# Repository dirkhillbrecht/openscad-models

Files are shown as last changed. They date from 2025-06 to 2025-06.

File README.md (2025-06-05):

# openscad-models

This repository contains OpenSCAD models I created for various purposes and want to share with the public.
The models may be related or unrelated, they may have external dependencies (but I like to prevent that)
and they might be from totally different realms.
Please refer to the `README`s in the subdirectories for actual information on the respective models.

As of June 2025, I use the official OpenSCAD 2021.1 for design.
This is the baseline version for the models published here.

## Projects

* [Case for the Waveshare 7 inch IPS HDMI display with USB touch, audio and VGA connectors](waveshare-7-inch-display-case/README.md)

## License

The license for the models published here is usually [CC-BY-SA 4.0](https://creativecommons.org/licenses/by-sa/4.0/deed.en) unless specified differently for certain models.
Look for `LICENSE` files here or in the subdirectories.

## History

I started 3D printing and designing by the end of 2023.
I created a number of models over time which I partly published on platforms like Printables.
So far, I used my local version control for the files.

As time went by and the number of my models increased, I wanted to have a better way of publishing
the OpenSCAD source files and especially of their version control.
So I decided to create this repository on Github which contains all this stuff
and makes it available to the public.

Have fun!

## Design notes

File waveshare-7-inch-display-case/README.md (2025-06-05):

# Case for the Waveshare 7 inch IPS HDMI display with USB touch, audio and VGA connectors

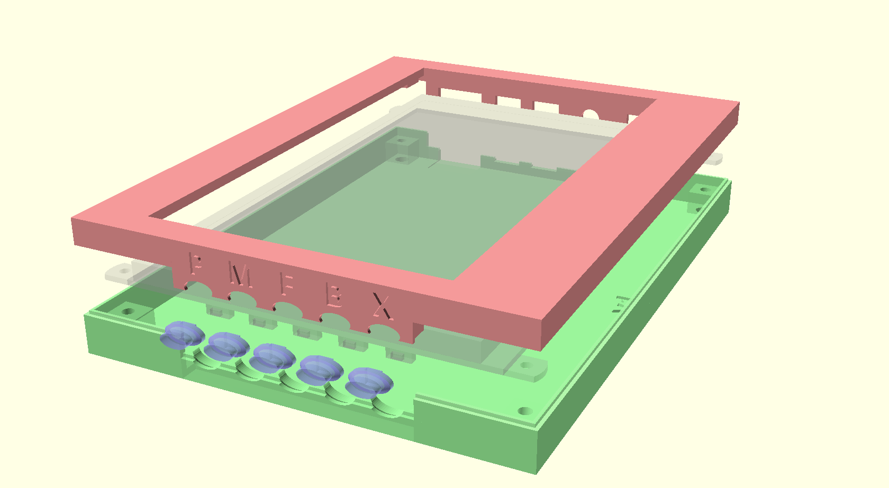
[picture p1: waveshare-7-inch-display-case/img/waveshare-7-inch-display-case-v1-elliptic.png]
Explosion sketch of the design Explosion sketch
  
*Explosion sketch*

Display case with holes for the connectors and buttons for the micro switches, held together by M3*16 screws/M3R nuts

## Overview

This model defines case for the Waveshare 7 inch display. It features

- minimum size around the display
- display is horizontally centered in the case
- knobs on the left side are pressed through buttons in the case
- buttons can be oval or rectangular
- connectors on the right side are accessible through seperate openings in the case

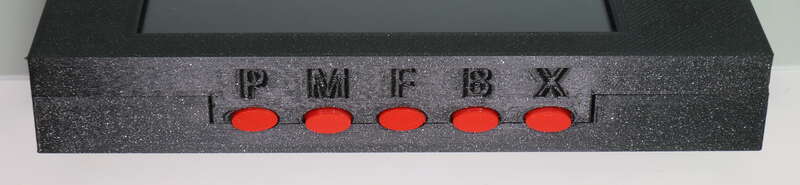
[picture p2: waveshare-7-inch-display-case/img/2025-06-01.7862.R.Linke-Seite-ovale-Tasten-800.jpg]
Picture of left side oval buttons Left side oval buttons
  
*Left side oval buttons*

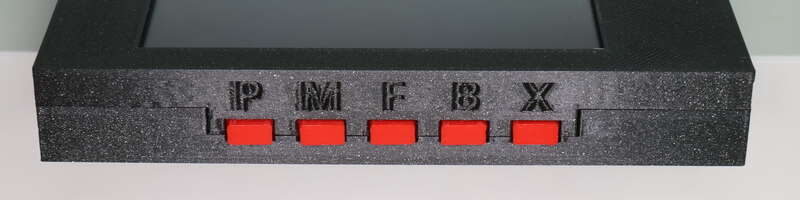
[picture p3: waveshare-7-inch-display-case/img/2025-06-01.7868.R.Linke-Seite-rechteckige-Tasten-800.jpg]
Picture of left side recangular buttons Left side rectangular buttons
  
*Left side rectangular buttons*

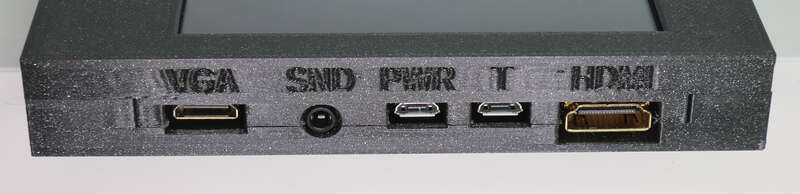
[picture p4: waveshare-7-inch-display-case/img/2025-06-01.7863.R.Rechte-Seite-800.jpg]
Picture of right side case openings Right side case openings
  
*Right side case openings*

The case consists of a top and bottom part and the five knobs.
Top and bottom part fit into each other using a surrounding notch.

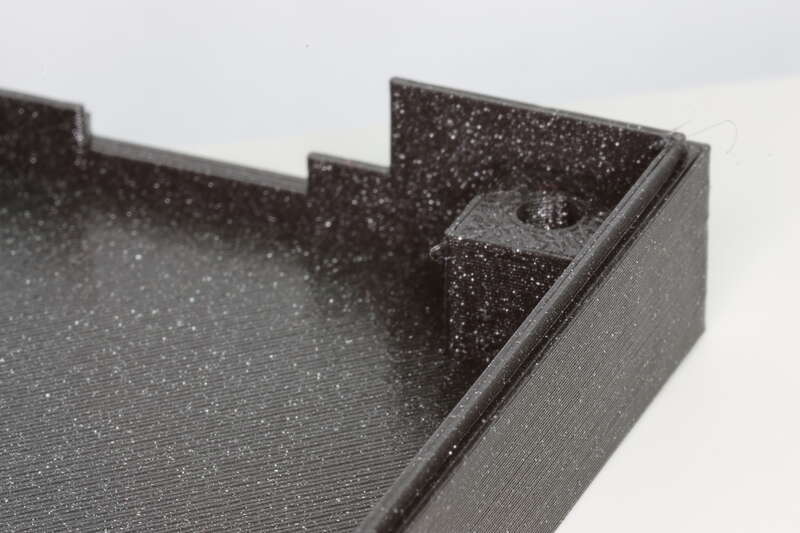
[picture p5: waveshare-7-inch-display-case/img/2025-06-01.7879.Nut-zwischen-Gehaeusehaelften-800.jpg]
Picture of notch on case part Notch on case part
  
*Notch on case part*

They are held together with four M3x16 screws and M3R rectangular nuts,
both nut heights fit. These screws also hold the display itself in place
and keep it between the two halfs of the case.

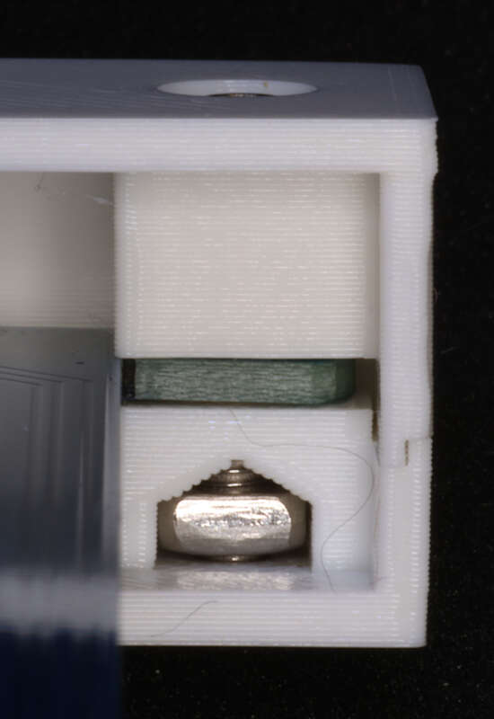
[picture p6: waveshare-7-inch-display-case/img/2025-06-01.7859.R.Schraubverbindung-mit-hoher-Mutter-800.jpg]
Picture of screw and nut holding the case together Screw and nut holding the case together
  
*Screw and nut holding the case together*

The case is printed without any supports. It uses 45° overhangs at the critical elements
which should be printed cleanly by any decent 3D printer. You might want to use 40% infill.

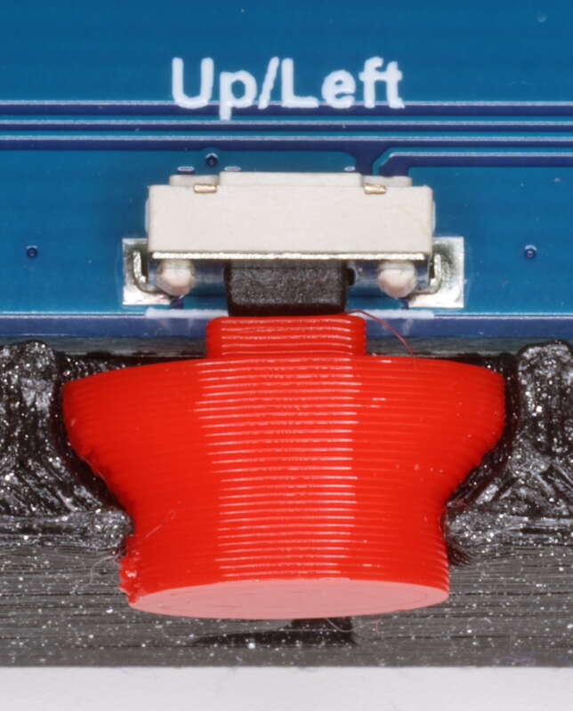
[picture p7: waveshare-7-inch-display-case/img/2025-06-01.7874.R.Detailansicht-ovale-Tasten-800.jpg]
Picture of oval left side button Detail of oval left side button
  
*Detail of oval left side button*

## Related projects

This design is also published on Printables where you can also find prerendered STL files.

* [Case with oval buttons](https://www.printables.com/model/1318542-case-for-the-waveshare-7-inch-ips-hdmi-display-wit)
* [Case with rectangular buttons](https://www.printables.com/model/1318554-case-for-the-waveshare-7-inch-ips-hdmi-display-wit)

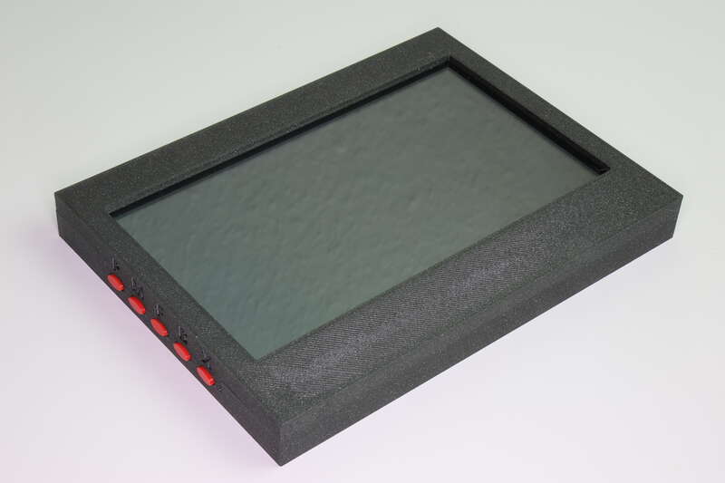
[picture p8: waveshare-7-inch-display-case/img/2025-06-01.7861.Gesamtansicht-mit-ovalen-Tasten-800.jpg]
Picture of case Case with display and oval buttons
  
*Case with display and oval buttons*

[← Back to project overview](../README.md)

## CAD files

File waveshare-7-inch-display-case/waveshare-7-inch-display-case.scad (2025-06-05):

/* Case for the Waveshare 7 inch IPS HDMI display with USB touch, audio and VGA connectors

## Overview

This model defines case for the Waveshare 7 inch display. It features

- minimum size around the display
- display is horizontally centered in the case
- buttons on the left side are pressed through knobs which can be either oval or rectangular
- connectors on the right side are accessible through seperate openings in the case

The case consists of a top and bottom part and the five knobs.
Top and bottom part fit into each other using a surrounding notch.
They are held together with four M3x16 screws and M3R rectangular nuts,
both nut heights fit. These screws also hold the display itself in place
and keep it between the two halfs of the case.

The case is printed without any supports. It uses 45° overhangs at the critical elements
which should be printed cleanly by any decent 3D printer.

## Using this definition file and printing the parts

This definition file is completely self-contained.
It consists of three parts:

1. Parameters describing the model, split into
    a. measurements taken from the physical artifact, i.e. the display
    b. additional lengths defined for certain properties of the case
    c. derived lengths from the above needed at several places
2. Modules describing
    a. the display itself to some detail to simplify the modelling process
    b. parts of the case and combinations of such parts to actually model the case
    c. different combinations of the most high-level modules for presentation and printing
3. Call to one of the combining top-level modules to actually produce some output

Use the highest level or combining modules to produce the output you need
and generate STL files from them.

All sizes in this file are given in millimeters.
Generally, x-axis is "width", y-axis is "depth" and z-axis is "height".
However, there are independently modelled parts (like the knobs)
which are _not_ designed in their actual orientation in the case.
For these elements, naming may seem inconsistent.

## Assembly

1. Print the top and bottom case parts and the five knobs.
2. Place the top part bottom-up on the workbench.
3. Push the four M3R nuts into the openings.
4. Place the display in the case.
5. Add the five knobs for the button in the openings on the side.
6. Put the bottom part of the case above the display and the top part.
7. Use the M3x16 screws to put everything together.

 */

// Version of the construction, increase if severe changes are made
version_string = "v1";

// Top-level switch: Should the buttons for the knobs on the left side
//   of the display be rectangular or elliptic?
//   This switch influences all parts of the case, so do not change it
//   for different parts of the same device.
left_button_rectangular = false;

// *******************
// *** Definitions ***
// *******************

// Part 1: Physical sizes, non-negotiable

// Main PCB
pcb_height = 1.6;  // Height of the display PCB
pcb_width = 165;   // Width of the display PCB
pcb_depth = 107;   // Depth of the PCB _without_ the four screw holders

// Holder parts of the PCB
holder_hole_diameter = 3;  // Diameter of the screw hole
holder_width = 8;          // Width of the holder (parallel to the long PCB side)
holder_depth = 8.5;        // Depth of the holder, longest distance to main PCB edge
holder_hole_from_edge = 3; // Distance between hole diameter and edge along the y axis
// Note: Along the x-axis/width, the hole is centered to the holder and needs no explicit measurement.

// Dimensions of the actual screen mouted on the PCB
screen_gross_width = 165;  // Width of the screen including its own frame (same as PCB width)
screen_gross_depth = 99.3; // Depth of the screen including frame
screen_gross_height = 7.3 - pcb_height; // Height of the screen _including_ gap between screen and PCB
screen_top_outer_gap = 2.1;  // Gap between screen and PCB top edge _outside_ the screen itself
// The "inner gaps" are the distance between the screen module edge and the actual screen with the pixels
screen_top_inner_gap = 4;       // Inner gap on the screen top side
screen_left_inner_gap = 3;      // Left inner gap
screen_right_inner_gap = 6.8;   // Right inner gap, note that it is different from the left gap!
screen_bottom_inner_gap = 8.7;  // Bottom inner gap, larger than top gap

// Dimension of knobs on the left side of the PCB
// These measurements describes the tiny knobs soldered onto the PCB
// Note: "width" and "depth" are swapped here as the measurements are taken from the knobs'
//   front side, i.e. rotated by 90°
knob_case_width = 7;  // Width of the "knob case", i.e. the white body of the knob
knob_case_height = 5.2 - pcb_height; // due to measuring
knob_case_depth = 2.25;  // Depth of the case, mainly needed for modelling the display itself
knob_bottom_distance = 0.84; // Distance between the actual (black) knob and the knob case edge
knob_height = 1.5;  // Height of the actual knob
knob_depth = 1.15;         // Depth of the knob, i.e. how long is the visible knob part when released
knob_depth_pressed = 0.7;  // Length of the visible knob part above the case when pressed
knob_width = 3;            // Width of the knob itself (centered in the knob case)
// The "knob area" is the full area of all five knobs as they are soldered on the PCB
knob_area_gross_width = 59; // from left of first case to right of last knob case
knob_area_bottom_gap = 39.5 - knob_case_width - holder_depth;  // Distance between the
//  outer edge of the knob case nearest to the PCB "bottom" edge, _excluding_ the screw holder

// USB pcb plug is the highest element on the PCB bottom
// This is _not_ one of the plugs of the right side but the PCB-mounted USB plug on the PCB's
//   bottom side. This is the "highest" element on the bottom side so the case needs to be
//   large enough to have space for it.
usb_pcb_plug_width = 4.7;
usb_pcb_plug_depth = 10;
usb_pcb_plug_height = 6;  // This is the most important dimension as it is the actual height
// The following measures give the position of the plug on the PCB. They are currently unused.
// They could be used to create a hole in the case for using the plug.
usb_pcb_plug_left_gap = 128.4 - usb_pcb_plug_width; // due to measuring
usb_pcb_plug_bottom_gap = 21.6 - usb_pcb_plug_depth; // due to measuring

// Now come the dimensions of the plugs on the right side of the display.
// The plug positions are measured from the bottom PCB edge _without_ the holders
//   to the nearer edge of the plug.

// HDMI plug data
hdmi_plug_width = 15;
hdmi_plug_depth = 11;
hdmi_plug_gross_height = 7.8 - pcb_height;
hdmi_plug_bottom_gap = 97.5 - hdmi_plug_width; // due to measuring, PCB corner WITHOUT holders

// USB plug data
usb_plug_width = 7.6;
usb_plug_depth = 5.7;
usb_plug_gross_height = 4.3 - pcb_height;
usb_plug_bottom_gapA = 83.2 - usb_plug_width - holder_depth;
usb_plug_bottom_gapB = 68.7 - usb_plug_width - holder_depth;

// Audio plug data
// Width, depth and height are measured for the cubic part of the plug,
//   the "diameter" lengths are for the circular part of the plug
audio_plug_width = 6.5;
audio_plug_depth = 12.1;
audio_plug_gross_height = 6.54 - pcb_height;
audio_plug_diameter = 5.4;
audio_plug_diameter_depth = 14.1 - audio_plug_depth;
audio_plug_bottom_gap = 43 - audio_plug_width;

// VGA plug data
vga_plug_width = 11.3;
vga_plug_depth = 8.1;
vga_plug_gross_height = 5 - pcb_height;
vga_plug_bottom_gap = 33.8 - vga_plug_width - holder_depth;


// Part 2: Dimensions of the case, can be changed

// Depth of chars embossed into case, mainly version number
char_depth = 0.8;

// Additional free space below the highest part on the bottom of the PCB
additional_bottom_space = 2;

// General strength of the walls of the case
wall_strength = 2;

// Gap between the case and the pcb in width and depth
pcb_gap = 0.5;

// Additional free space above the top layer of the screen
additional_top_space = 1;

// additional space around holes for the plug on the right
right_side_plugs_frame = 1.2;

// additional space left and right of the right-side plug holes in the case
right_side_walls_frame = 5;

// Final adjustment of hole height on both sides
physical_height_correction = -1;
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

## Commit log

2025-06-05 Add model of case for Waveshare 7 inch display
    [waveshare-7-inch-display-case.scad]
2025-06-05 waveshare-7-inch: Add links to Printables projects
